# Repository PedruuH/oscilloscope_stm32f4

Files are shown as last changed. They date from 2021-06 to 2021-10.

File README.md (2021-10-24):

# Oscilloscope with STM32F411

### Introdução

Projeto de hardware criado para cumprimento curricular da materia de [Sistemas Embarcados](https://www.sei.ufu.br/sei/modulos/pesquisa/md_pesq_documento_consulta_externa.php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). Neste repositório possui a cocepção de três possiveis roteamentos de trilhas em PCB, sendo o [segundo](https://github.com/PedruuH/oscilloscope_stm32f4/blob/main/oscilloscope_stm32F4%20-%202.kicad_pcb) o adotado como final.

### Imagens da PCB

Parte superior:

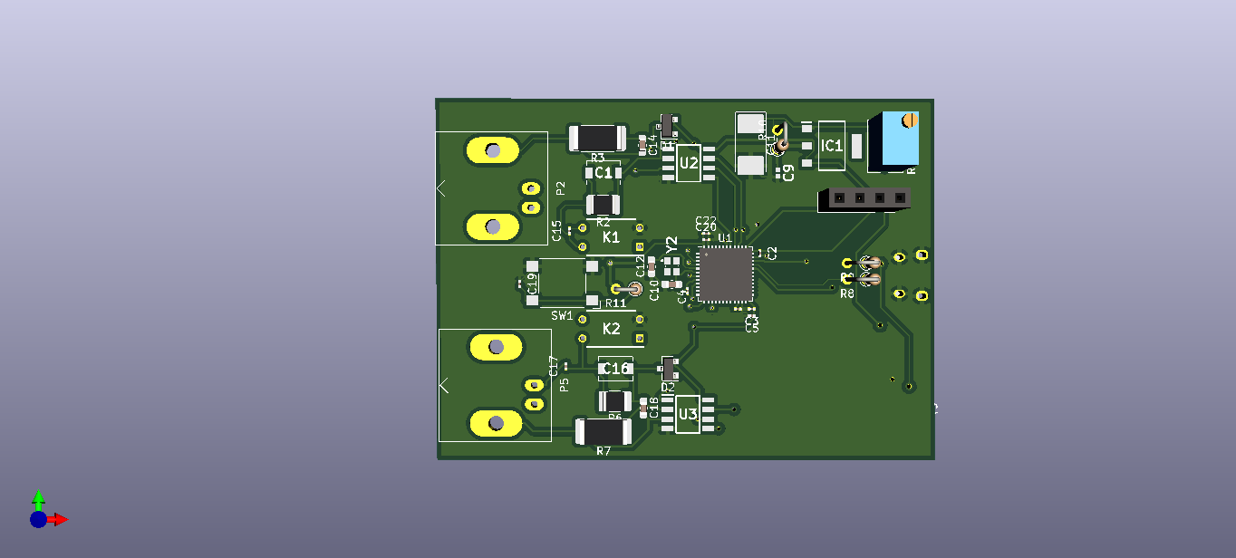
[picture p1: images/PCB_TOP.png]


Parte inferior:

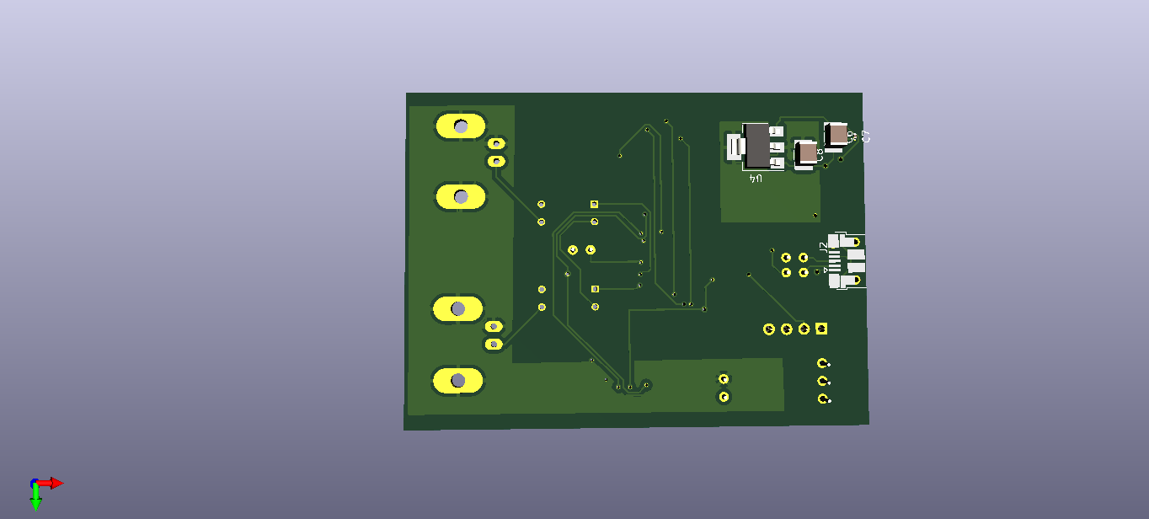
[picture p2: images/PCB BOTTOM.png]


### Fabricação

Foram gerados os Gerbers de fabricação e se encontram na pasta [Fabricação](https://github.com/PedruuH/oscilloscope_stm32f4/tree/main/Fabrica%C3%A7%C3%A3o), contudo, é fortemente recomendado abrir o projeto e adaptar o PCB de acordo com a empresa de fabricação de sua escolha.

### Software usado

Utilizado a ferramenta open source de design de eletronicos [KiCad 5.1.10](https://www.kicad.org/).

# Licensing

Copyright 2020 Pedro Henrique R M Santos.

Licensed under the Apache License, Version 2.0 (the "License");

you may not use this file except in compliance with the License.

You may obtain a copy of the License at [http://www.apache.org/licenses/LICENSE-2.0](http://www.apache.org/licenses/LICENSE-2.0)

Unless required by applicable law or agreed to in writing, software

distributed under the License is distributed on an "AS IS" BASIS,

WITHOUT WARRANTIES OR CONDITIONS OF ANY KIND, either express or implied.

See the License for the specific language governing permissions and

limitations under the License.

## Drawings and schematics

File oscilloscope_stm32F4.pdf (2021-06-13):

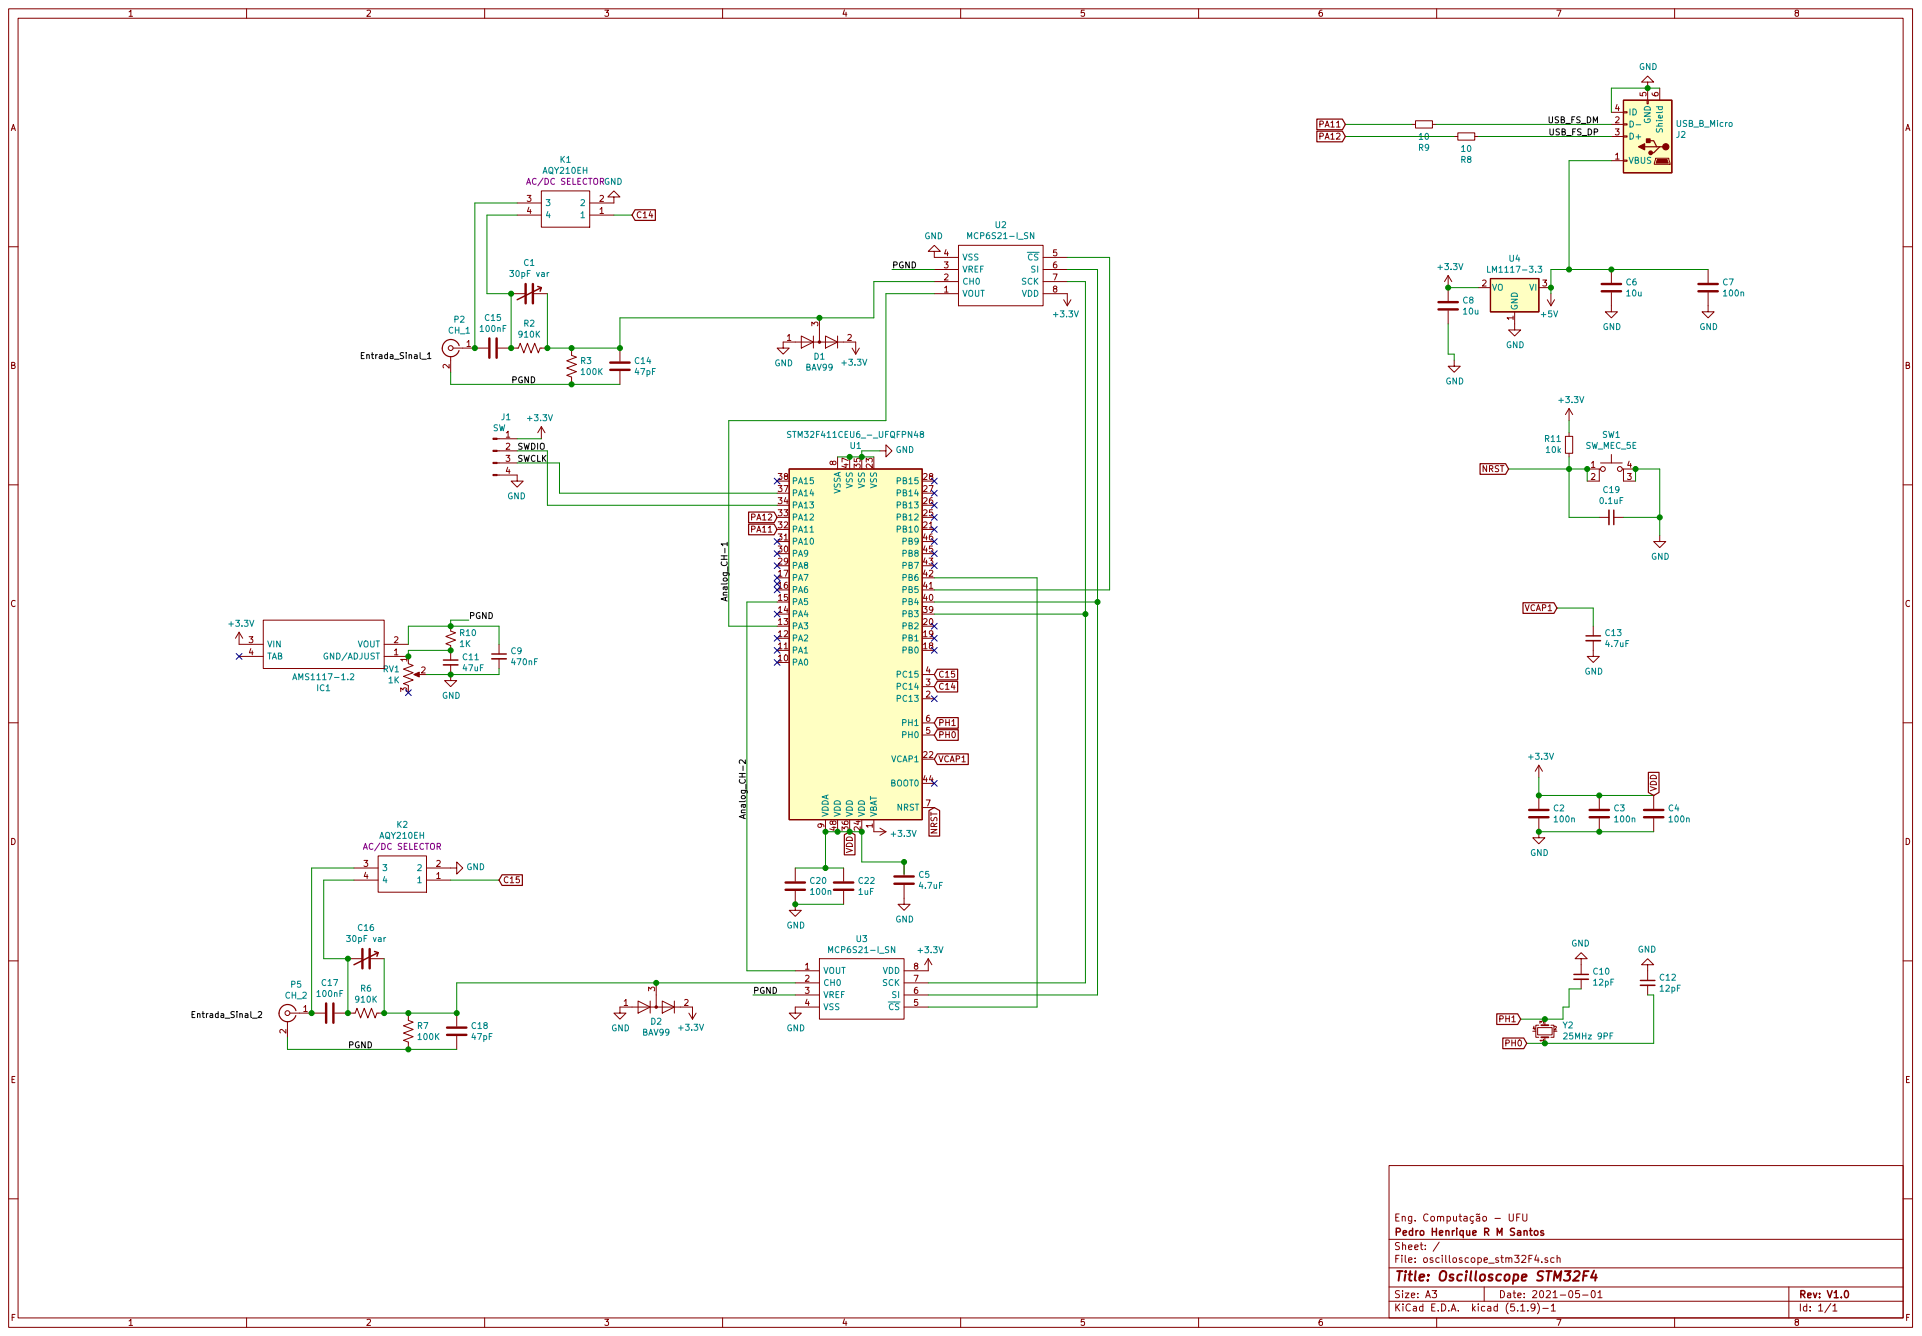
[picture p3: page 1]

Eng. Computação - UFU
File: oscilloscope_stm32F4.sch Sheet: / Pedro Henrique R M Santos

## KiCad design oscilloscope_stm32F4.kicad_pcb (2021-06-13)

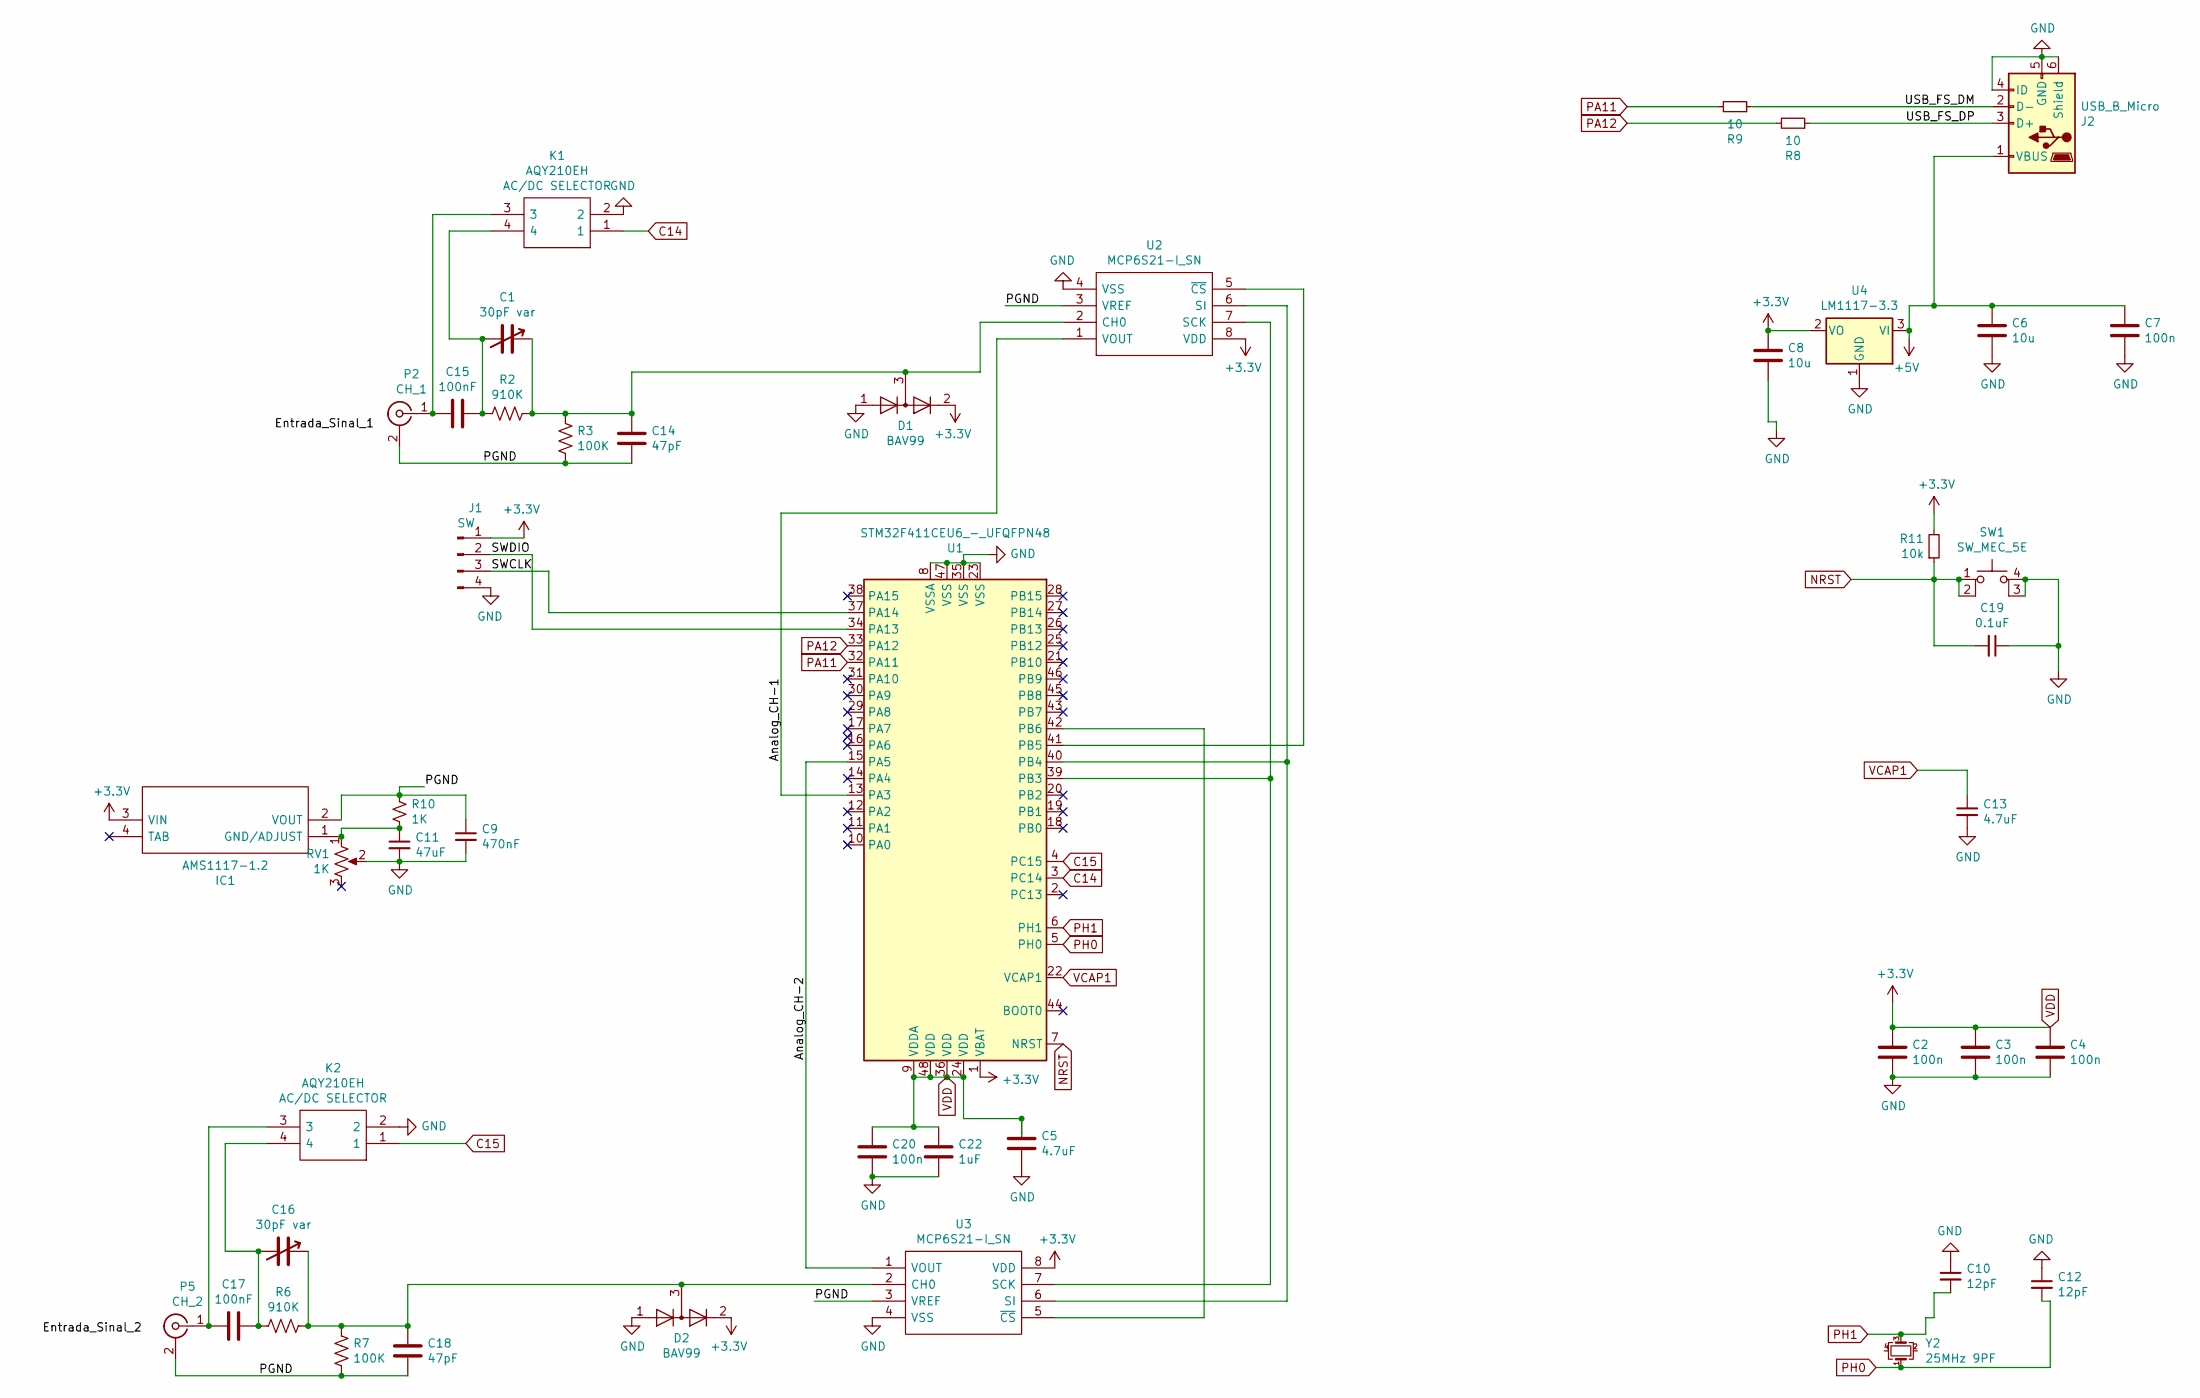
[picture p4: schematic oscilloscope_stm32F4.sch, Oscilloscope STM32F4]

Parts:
C1, C16: 30pF var; JZ300
C2, C3, C4, C7, C20: 100n; C_0805_2012Metric_Pad1.18x1.45mm_HandSolder
C5, C13: 4.7uF; C_0805_2012Metric_Pad1.18x1.45mm_HandSolder
C6, C8: 10u; C_1210_3225Metric_Pad1.33x2.70mm_HandSolder
C9: 470nF; CAPC1005X55N
C10, C12: 12pF; C_0603_1608Metric_Pad1.08x0.95mm_HandSolder
C11: 47uF; CP_EIA-7132-20_AVX-U
C14, C18: 47pF; C_0603_1608Metric_Pad1.08x0.95mm_HandSolder
C15, C17: 100nF; C_0805_2012Metric_Pad1.18x1.45mm_HandSolder
C19: 0.1uF; C_0805_2012Metric_Pad1.18x1.45mm_HandSolder
C22: 1uF; C_0805_2012Metric_Pad1.18x1.45mm_HandSolder
D1, D2: BAV99; SOT-23
IC1: AMS1117-1.2; SOT229P700X180-4N; Manufacturer_Part_Number AMS1117-1.2
J1: SW; PinSocket_1x04_P2.54mm_Vertical
J2: USB_B_Micro; USB_Micro-B_Amphenol_10103594-0001LF_Horizontal
K1, K2: AQY210EH; DIP762W47P254L478H340Q4N; Mouser Part Number 769-AQY210EH
P2: CH_1; BNC_Amphenol_B6252HB-NPP3G-50_Horizontal
P5: CH_2; BNC_Amphenol_B6252HB-NPP3G-50_Horizontal
R2, R6: 910K; R_1210_3225Metric_Pad1.30x2.65mm_HandSolder
R3, R7: 100K; R_2512_6332Metric_Pad1.40x3.35mm_HandSolder
R8, R9: 10; R_Axial_DIN0204_L3.6mm_D1.6mm_P5.08mm_Horizontal
R10: 1K; R_Axial_DIN0204_L3.6mm_D1.6mm_P5.08mm_Horizontal
R11: 10k; R_Axial_DIN0204_L3.6mm_D1.6mm_P5.08mm_Horizontal
RV1: 1K; Potentiometer_Bourns_3266Y_Vertical
SW1: SW_MEC_5E; SW_SPST_Omron_B3FS-100xP
U1: STM32F411CEU6_-_UFQFPN48; QFN-48-1EP_7x7mm_P0.5mm_EP5.6x5.6mm
U2, U3: MCP6S21-I_SN; SOIC127P600X175-8N; Manufacturer_Part_Number MCP6S21-I/SN; Mouser Part Number 579-MCP6S21-I/SN
U4: LM1117-3.3; SOT-223-3_TabPin2
Y2: 25MHz 9PF; CrystalSMD

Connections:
+5V: C6.1, C7.1, J2.1 (VBUS), U4.3 (VI)
/Analog_CH-1: U1.13 (PA3), U2.1 (VOUT)
/Analog_CH-2: U1.15 (PA5), U3.1 (VOUT)
/PGND: C9.1, C14.2, C18.2, IC1.2 (VOUT), P2.2 (Ext), P5.2 (Ext), R3.2, R7.2, R10.1, U2.3 (VREF), U3.3 (VREF)
/SWCLK: J1.3, U1.37 (PA14)
/SWDIO: J1.2, U1.34 (PA13)
/USB_FS_DM: J2.2 (D-), R9.1
/USB_FS_DP: J2.3 (D+), R8.1
C14: K1.1, U1.3 (PC14)
C15: K2.1, U1.4 (PC15)
GND: C2.2, C3.2, C4.2, C5.2, C6.2, C7.2, C8.2, C9.2, C10.1, C11.2, C12.1, C13.2, C19.1, C20.2, C22.2, D1.1 (K), D2.1 (K), J1.4, J2.4 (ID), J2.5 (GND), J2.6 (Shield), K1.2, K2.2, RV1.2, SW1.3 (K), SW1.4 (A), U1.8 (VSSA), U1.23 (VSS), U1.35 (VSS), U1.47 (VSS), U2.4 (VSS), U3.4 (VSS), U4.1 (GND)
NRST: C19.2, R11.1, SW1.1, SW1.2, U1.7 (NRST)
unnamed: C1.1, C14.1, D1.3 (K), R2.1, R3.1, U2.2 (CH0)
unnamed: C1.2, C15.1, K1.4, R2.2
unnamed: C11.1, IC1.1 (GND/ADJUST), R10.2, RV1.1
unnamed: C15.2, K1.3, P2.1 (In)
unnamed: C16.1, C18.1, D2.3 (K), R6.1, R7.1, U3.2 (CH0)
unnamed: C16.2, C17.1, K2.4, R6.2
unnamed: C17.2, K2.3, P5.1 (In)
unnamed: U1.39 (PB3), U2.7 (SCK), U3.7 (SCK)
unnamed: U1.40 (PB4), U2.6 (SI), U3.6 (SI)
unnamed: U1.41 (PB5), U2.5 (~CS)
unnamed: U1.42 (PB6), U3.5 (~CS)
PA11: R9.2, U1.32 (PA11)
PA12: R8.2, U1.33 (PA12)
PH0: C12.2, U1.5 (PH0), Y2.1
PH1: C10.2, U1.6 (PH1), Y2.3
VCAP1: C13.1, U1.22 (VCAP1)
VDD: C2.1, C3.1, C4.1, C5.1, C8.1, C20.1, C22.1, D1.2 (A), D2.2 (A), IC1.3 (VIN), J1.1, R11.2, U1.1 (VBAT), U1.9 (VDDA), U1.24 (VDD), U1.36 (VDD), U1.48 (VDD), U2.8 (VDD), U3.8 (VDD), U4.2 (VO)

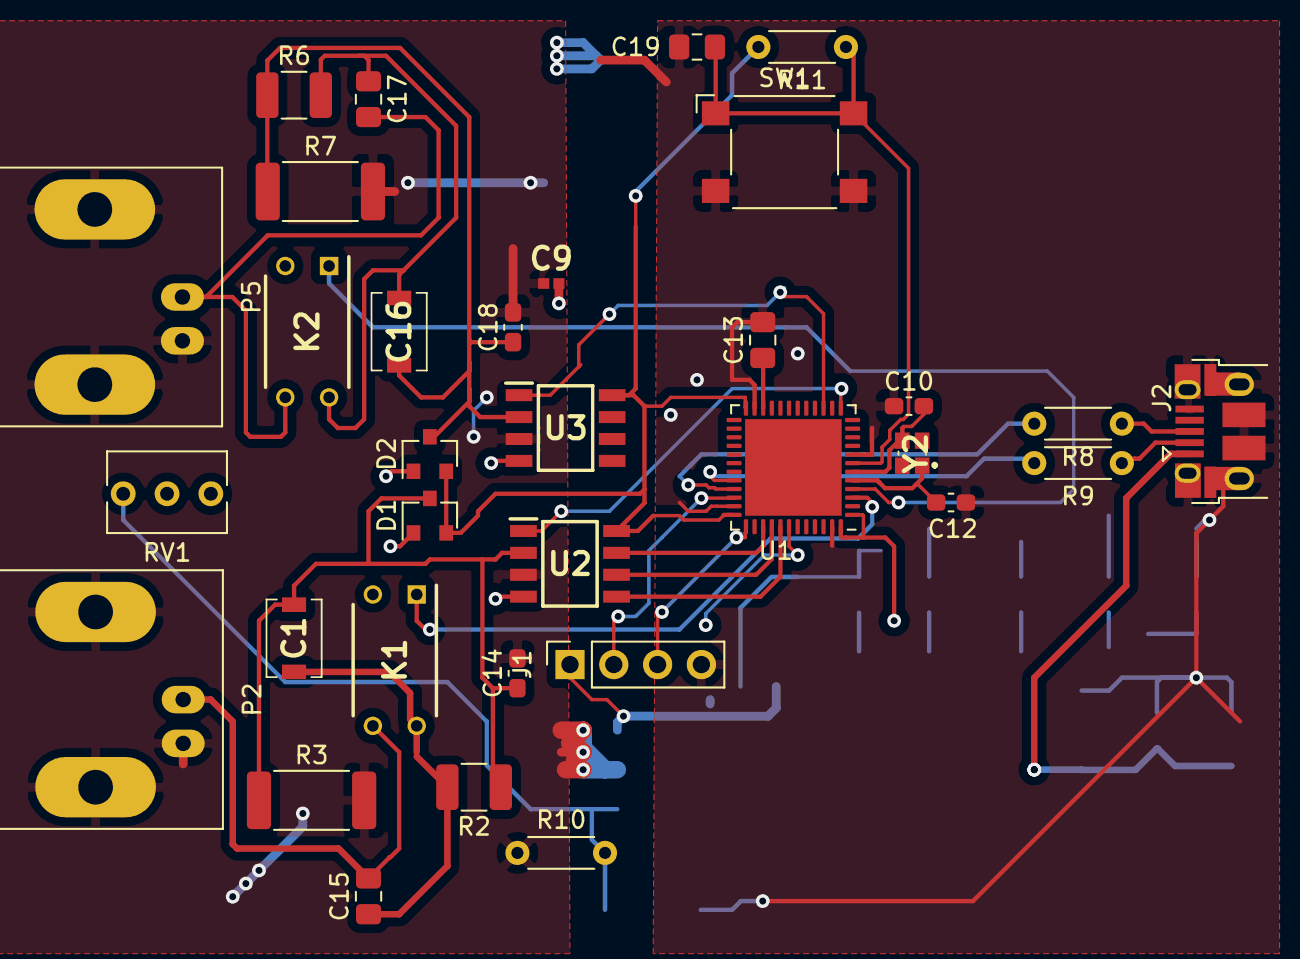
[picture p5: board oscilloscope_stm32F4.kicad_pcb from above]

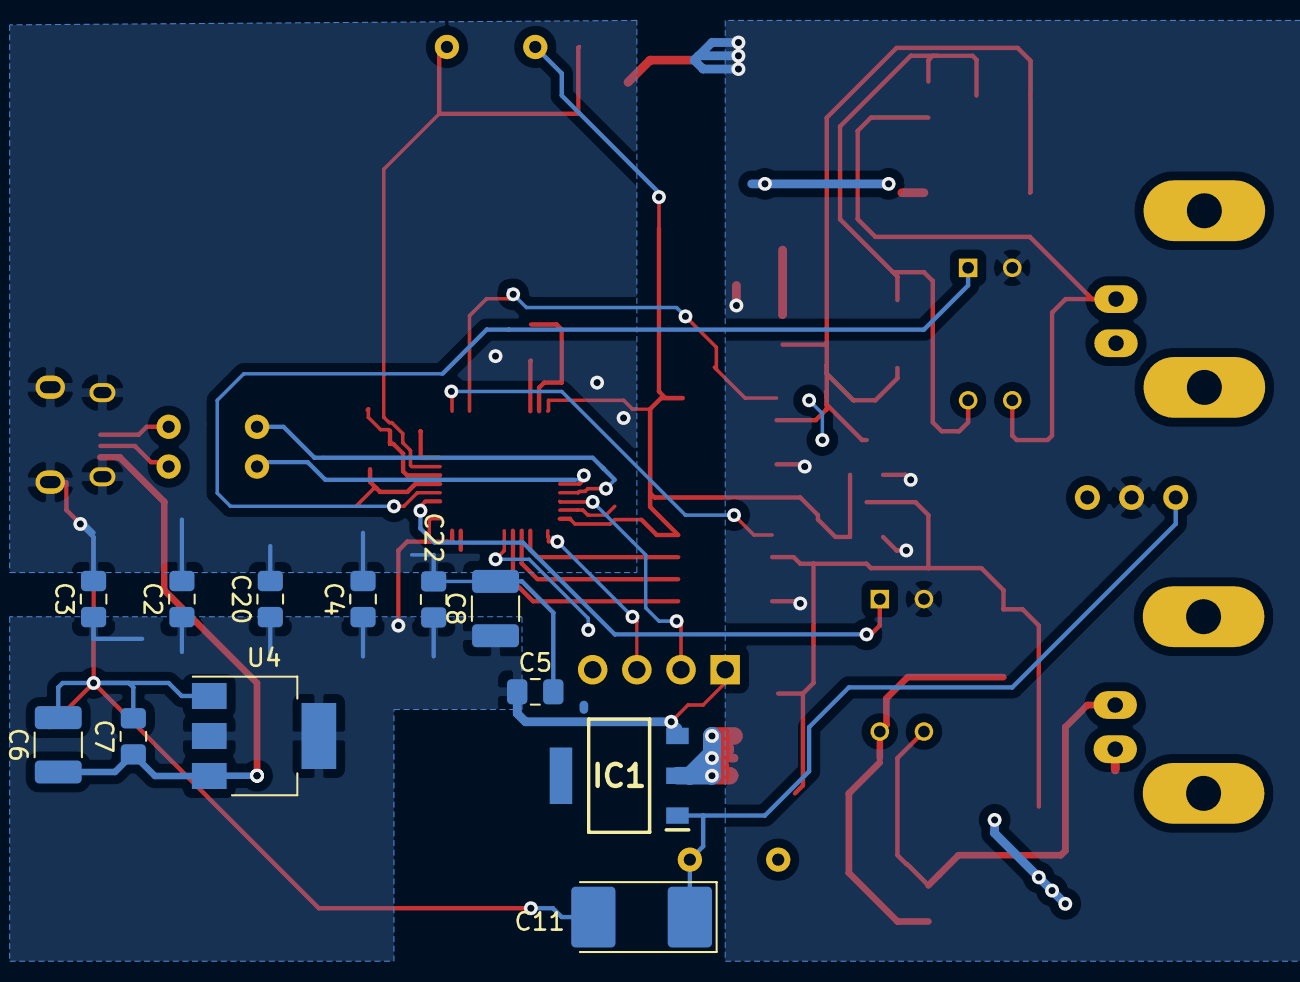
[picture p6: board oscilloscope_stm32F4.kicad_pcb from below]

Board: 2 copper layers, 45 parts (12 on the bottom side), 29 nets.

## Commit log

2021-05-07 Inicio Projeto
    [oscilloscope_stm32F4-folha2.sch, oscilloscope_stm32F4.kicad_pcb, oscilloscope_stm32F4.sch]
2021-05-08 atualização
    [oscilloscope_stm32F4-folha2.sch, oscilloscope_stm32F4.sch]
2021-10-24 exclude paste oscilloscope_stm32f4
    [oscilloscope_stm32F4 - 2.kicad_pcb, oscilloscope_stm32F4 - 3.kicad_pcb, oscilloscope_stm32F4.kicad_pcb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]
2021-10-24 new images and drl
    [oscilloscope_stm32F4 - 2-NPTH-drl_map.gbr, oscilloscope_stm32F4 - 2-NPTH.drl, oscilloscope_stm32F4 - 2-PTH-drl_map.gbr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]
